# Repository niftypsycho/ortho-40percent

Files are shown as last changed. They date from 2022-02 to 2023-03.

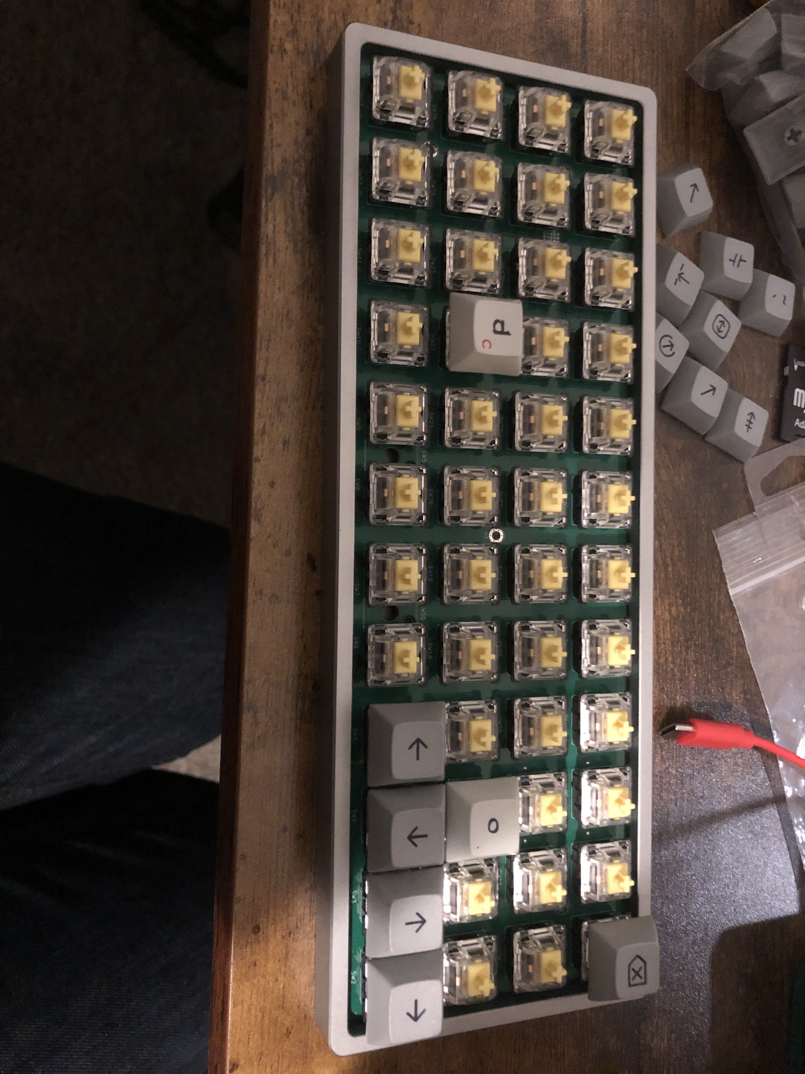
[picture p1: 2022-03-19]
images/IMG_2474.JPG

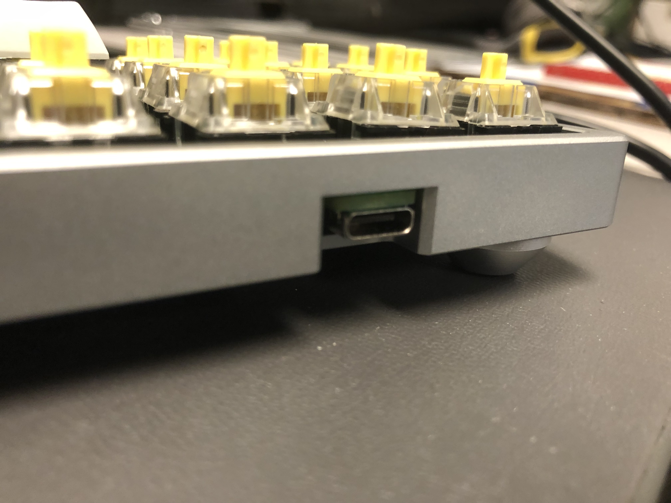
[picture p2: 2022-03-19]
images/IMG_2481.JPG

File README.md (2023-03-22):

# ortho-40percent
 A 40% ortholinear mechanical keyboard with hotswaps. Designed to become familiar with keyboard fabrication and remove the need for soldering.  
 

# INSTRUCTIONS FOR FLASHING  
If you do not already have QMK MSYS installed do so here: https://msys.qmk.fm/  
After installing run `qmk setup`  
Clone the folder labeled mvfang located in the SOFTWARE folder and paste it into qmk_firmware/keyboards  
Test your environment by running `qmk compile -kb mvfang -km default`. This will compile the default keymap included in the mvfang folder.  
  
# EDITING AND FLASHING YOUR KEYMAP  
mvFang uses a nonstandard row-column setup than most custom keyboards. However, this has been basically abstracted away through the config.h and mvfang.h files. Unless you are absolutely certain you know what you are doing you should never interact with those files.  
  
Because this is a hotswap keyboard the option exists to use a single 2u key in the space occupied by the 5th and 6th, and 7th and 8th 1u keys respectively. The config files leave these 2u spaces active as mappable keys during all flashes.  
  
STEP 1 - Create a new keymap  
Copy the `default` keymap by running `qmk new-keymap`. Once it is created open the `keymap.c` file with any text editor. The keycodes are laid out to match the key position with the optional 2 2u keys on the last row. For a list of possible keycodes look at this doc: https://docs.qmk.fm/#/keycodes  
  
STEP 2 - Adding additional layers  
Adding layers is possible as long as you keep the same organization provided in the `LAYOUT_ALL`.  
  
STEP 3 - Flashing your custom keymap  
Make sure the keyboard is not inside the case, or that you have access to the reset button located on the bottom of the board. With the keyboard plugged into your computer double-tap the reset button. You should hear the USB connect noise (if you're on Windows) which means your board is in bootloader mode. Run `qmk flash -kb mvfang -km <my_keymap>`. If everything completes, congratulations.

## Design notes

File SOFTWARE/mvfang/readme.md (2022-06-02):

# mvfang

mvfang

*A short description of the keyboard/project*

* Keyboard Maintainer: [Christian Pavkovich](https://github.com/niftypsycho)
* Hardware Supported: *The PCBs, controllers supported*
* Hardware Availability: *Links to where you can find this hardware*

Make example for this keyboard (after setting up your build environment):

    make mvfang:default

Flashing example for this keyboard:

    make mvfang:default:flash

See the [build environment setup](https://docs.qmk.fm/#/getting_started_build_tools) and the [make instructions](https://docs.qmk.fm/#/getting_started_make_guide) for more information. Brand new to QMK? Start with our [Complete Newbs Guide](https://docs.qmk.fm/#/newbs).

## Bootloader

Enter the bootloader in 3 ways:

* **Bootmagic reset**: Hold down the key at (0,0) in the matrix (usually the top left key or Escape) and plug in the keyboard
* **Physical reset button**: Briefly press the button on the back of the PCB - some may have pads you must short instead
* **Keycode in layout**: Press the key mapped to `RESET` if it is available

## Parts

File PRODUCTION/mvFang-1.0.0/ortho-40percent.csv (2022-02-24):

Source: | C:\Users\Christian\Documents\GitHub\ortho-40percent\ortho-40percent.sch
Date: | 7/28/2021 2:41:26 PM
Tool: | Eeschema (5.1.4)-1
Generator: | C:\Program Files\KiCad\bin\scripting\plugins/bom_csv_grouped_by_value_with_fp.py
Component Count: | 128
Qnty | Ref | Manufacturer | MPN | Package | Description
1 | C3, | KEMET | T520A106M010ATE080 | 1206
8 | C4, C6, C7, C8, C9, C1, C2, C5, | KEMET | C0805C104M5RACTU | 0805
50 | D1, D8, D15, D22, D29, D35, D41, D2, D9, D16, D23, D30, D42, D3, D10, D17, D24, D31, D37, D43, D49, D4, D11, D18, D25, D32, D38, D44, D50, D5, D12, D19, D26, D33, D39, D45, D6, D13, D20, D34, D40, D46, D7, D14, D21, D28, D27, D48, D47, D36, | SMC Diode Solutions | 1N4148WTR | SOD-123
1 | F1, | Bel Fuse Inc. | 0ZCJ0050FF2G | 1206 | Fuse
5 | H1, H2, H3, H4, H5, | DNP | DNP | DNP
1 | J1, | Amphenol ICC (Commercial Products) | 12401598E4#2A | Surface Mount, Right Angle; Through Hole
1 | L1, | Taiyo Yuden | FBMJ3216HM600-T | 1206
6 | R1, R2, R4, R3, R6, R5, | Yageo | RC0805FR-0710KL | 0805
1 | SW1, | C&K | RS-187R05A2-DS MT RT | Surface Mount
48 | SW2, SW9, SW16, SW23, SW30, SW36, SW42, SW3, SW10, SW17, SW24, SW31, SW43, SW4, SW11, SW18, SW25, SW32, SW38, SW44, SW5, SW12, SW19, SW26, SW33, SW39, SW45, SW6, SW13, SW20, SW27, SW34, SW40, SW46, SW7, SW14, SW21, SW35, SW41, SW47, SW8, SW15, SW22, SW29, SW28, SW49, SW48, SW37, | DNP | DNP | 1u
2 | SW50, SW51, | DNP | DNP | 2u
1 | TVS1, | Rohm Semiconductor | SMF6V0TFTR | SOD-123F
1 | U1, | Texas Instruments | TPD4E05U06DQAR | UFDFN-10 | TVS DIODE 5.5V 14V 10SON
1 | U2, | Microchip Technology | ATMEGA32U4-MU | VQFN-44-1EP | IC MCU 8BIT 32KB FLASH 44VQFN
1 | Y1, | Kyocera International Inc. Electronic Components | CX3225SB16000D0GZJC1 | 4-SMD | Generic crystal with 4 leads

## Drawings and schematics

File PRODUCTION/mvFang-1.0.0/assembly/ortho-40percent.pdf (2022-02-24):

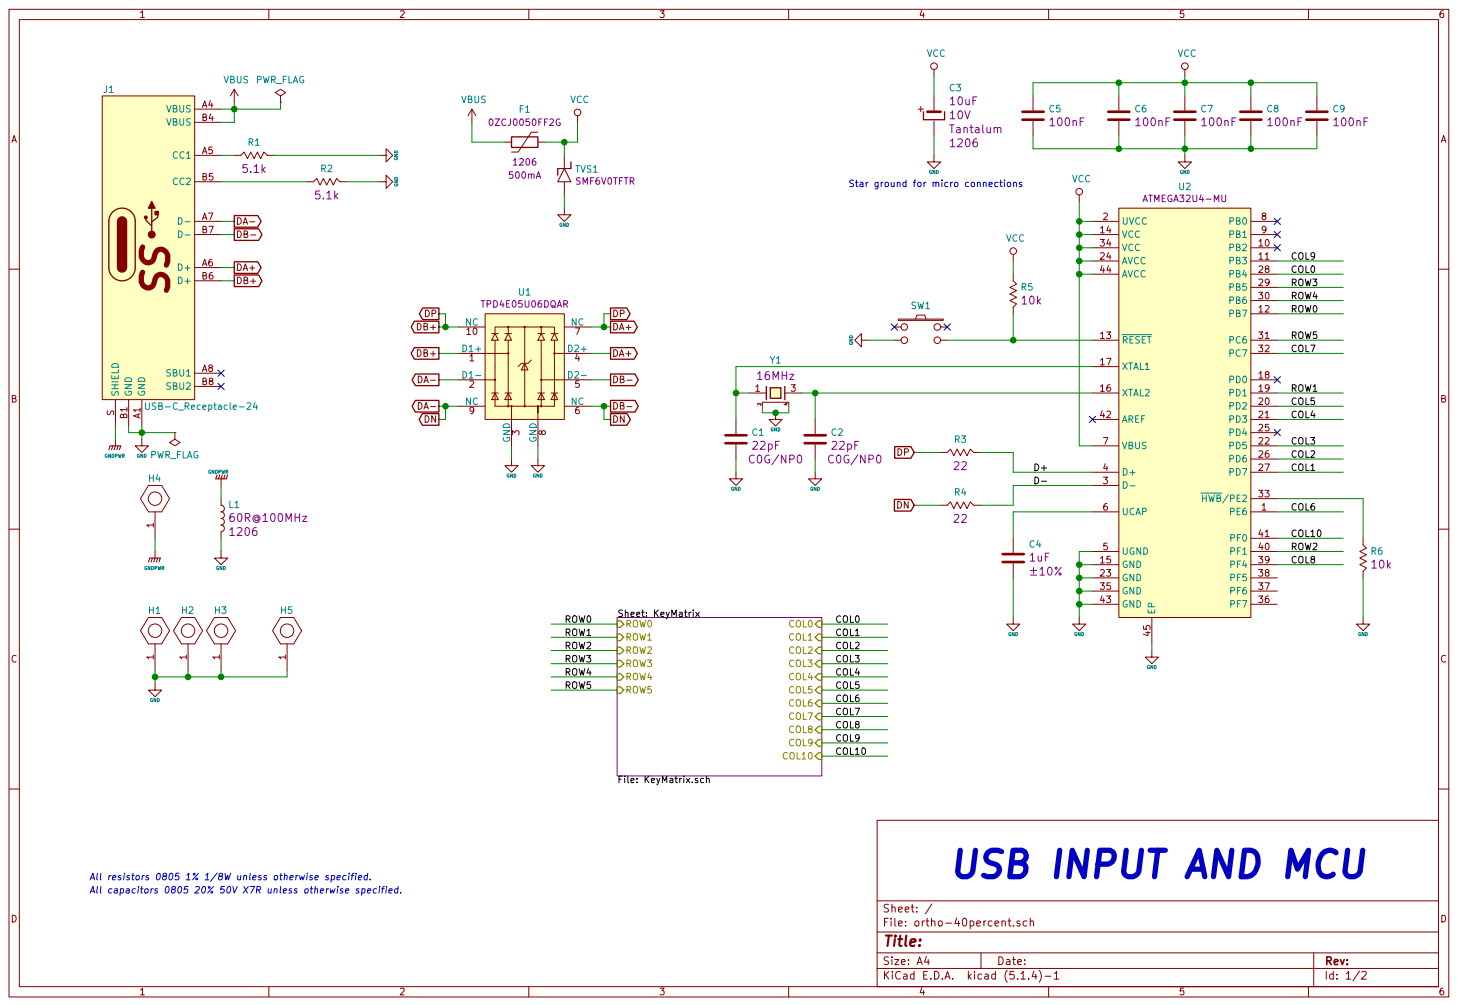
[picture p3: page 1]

Star ground for micro connections

File: ortho-40percent.sch Sheet: / Sheet: KeyMatrix

USB INPUT AND MCU

All capacitors 0805 20% 50V X7R unless otherwise specified.

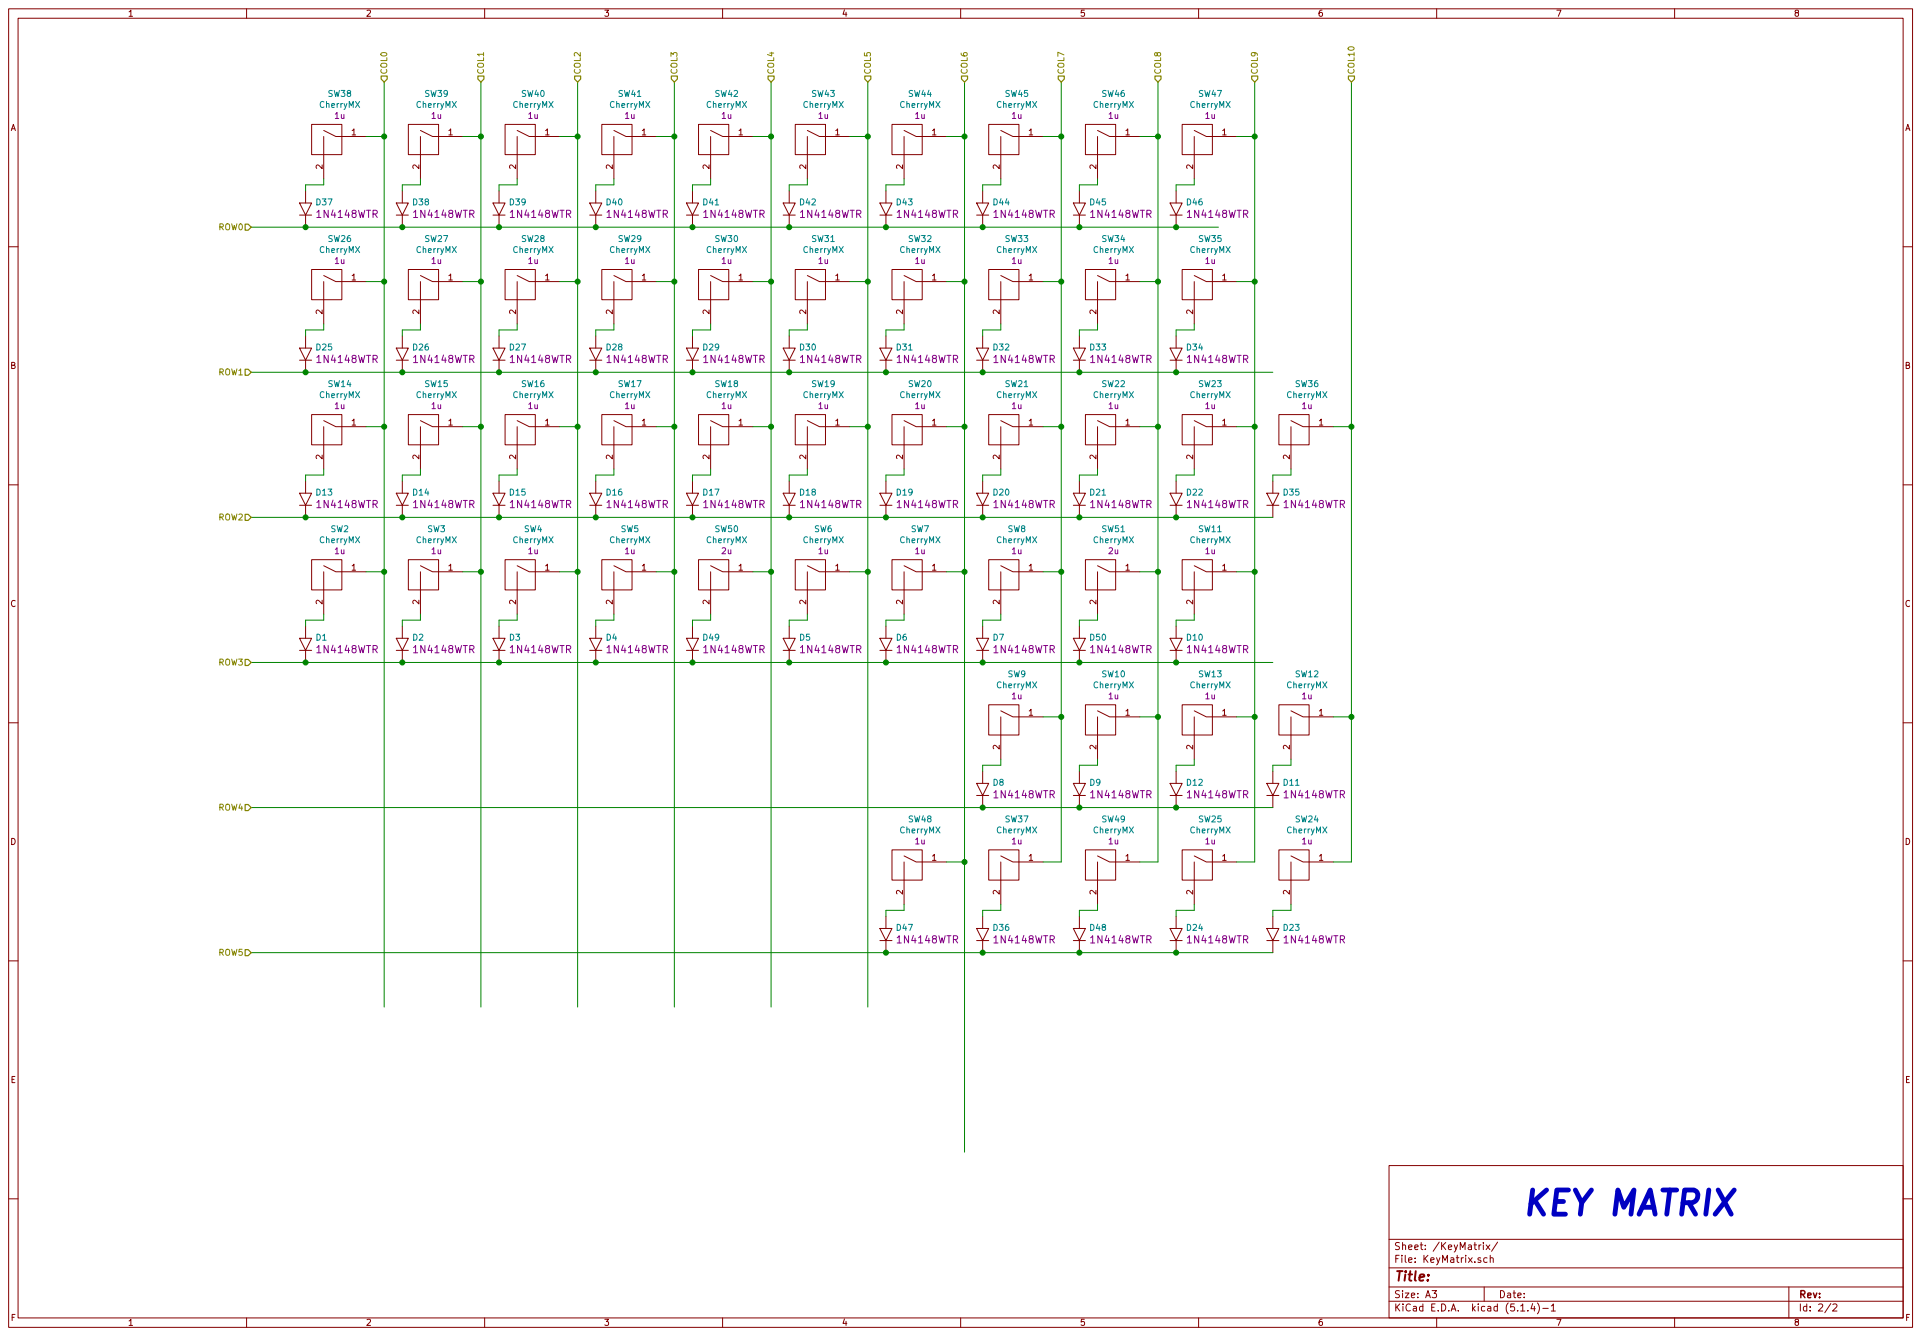
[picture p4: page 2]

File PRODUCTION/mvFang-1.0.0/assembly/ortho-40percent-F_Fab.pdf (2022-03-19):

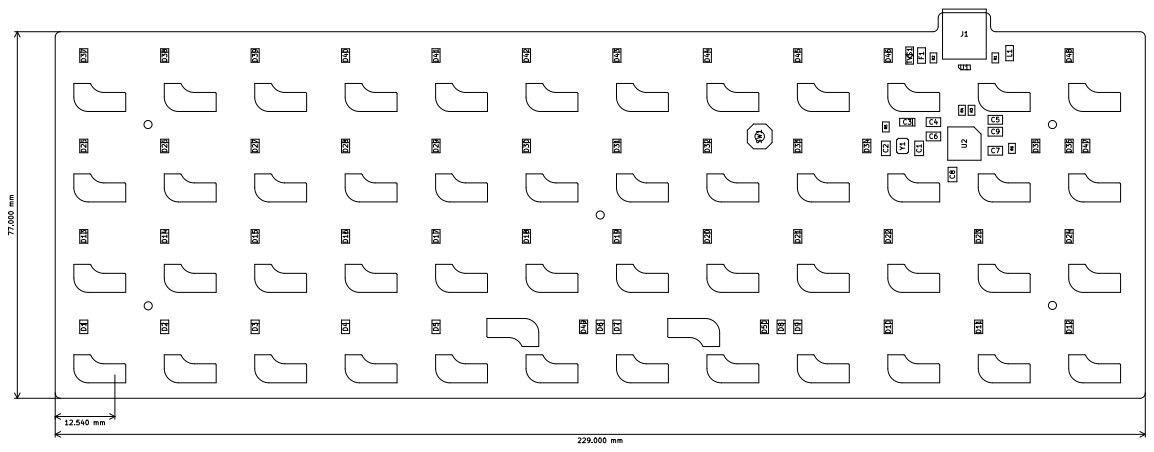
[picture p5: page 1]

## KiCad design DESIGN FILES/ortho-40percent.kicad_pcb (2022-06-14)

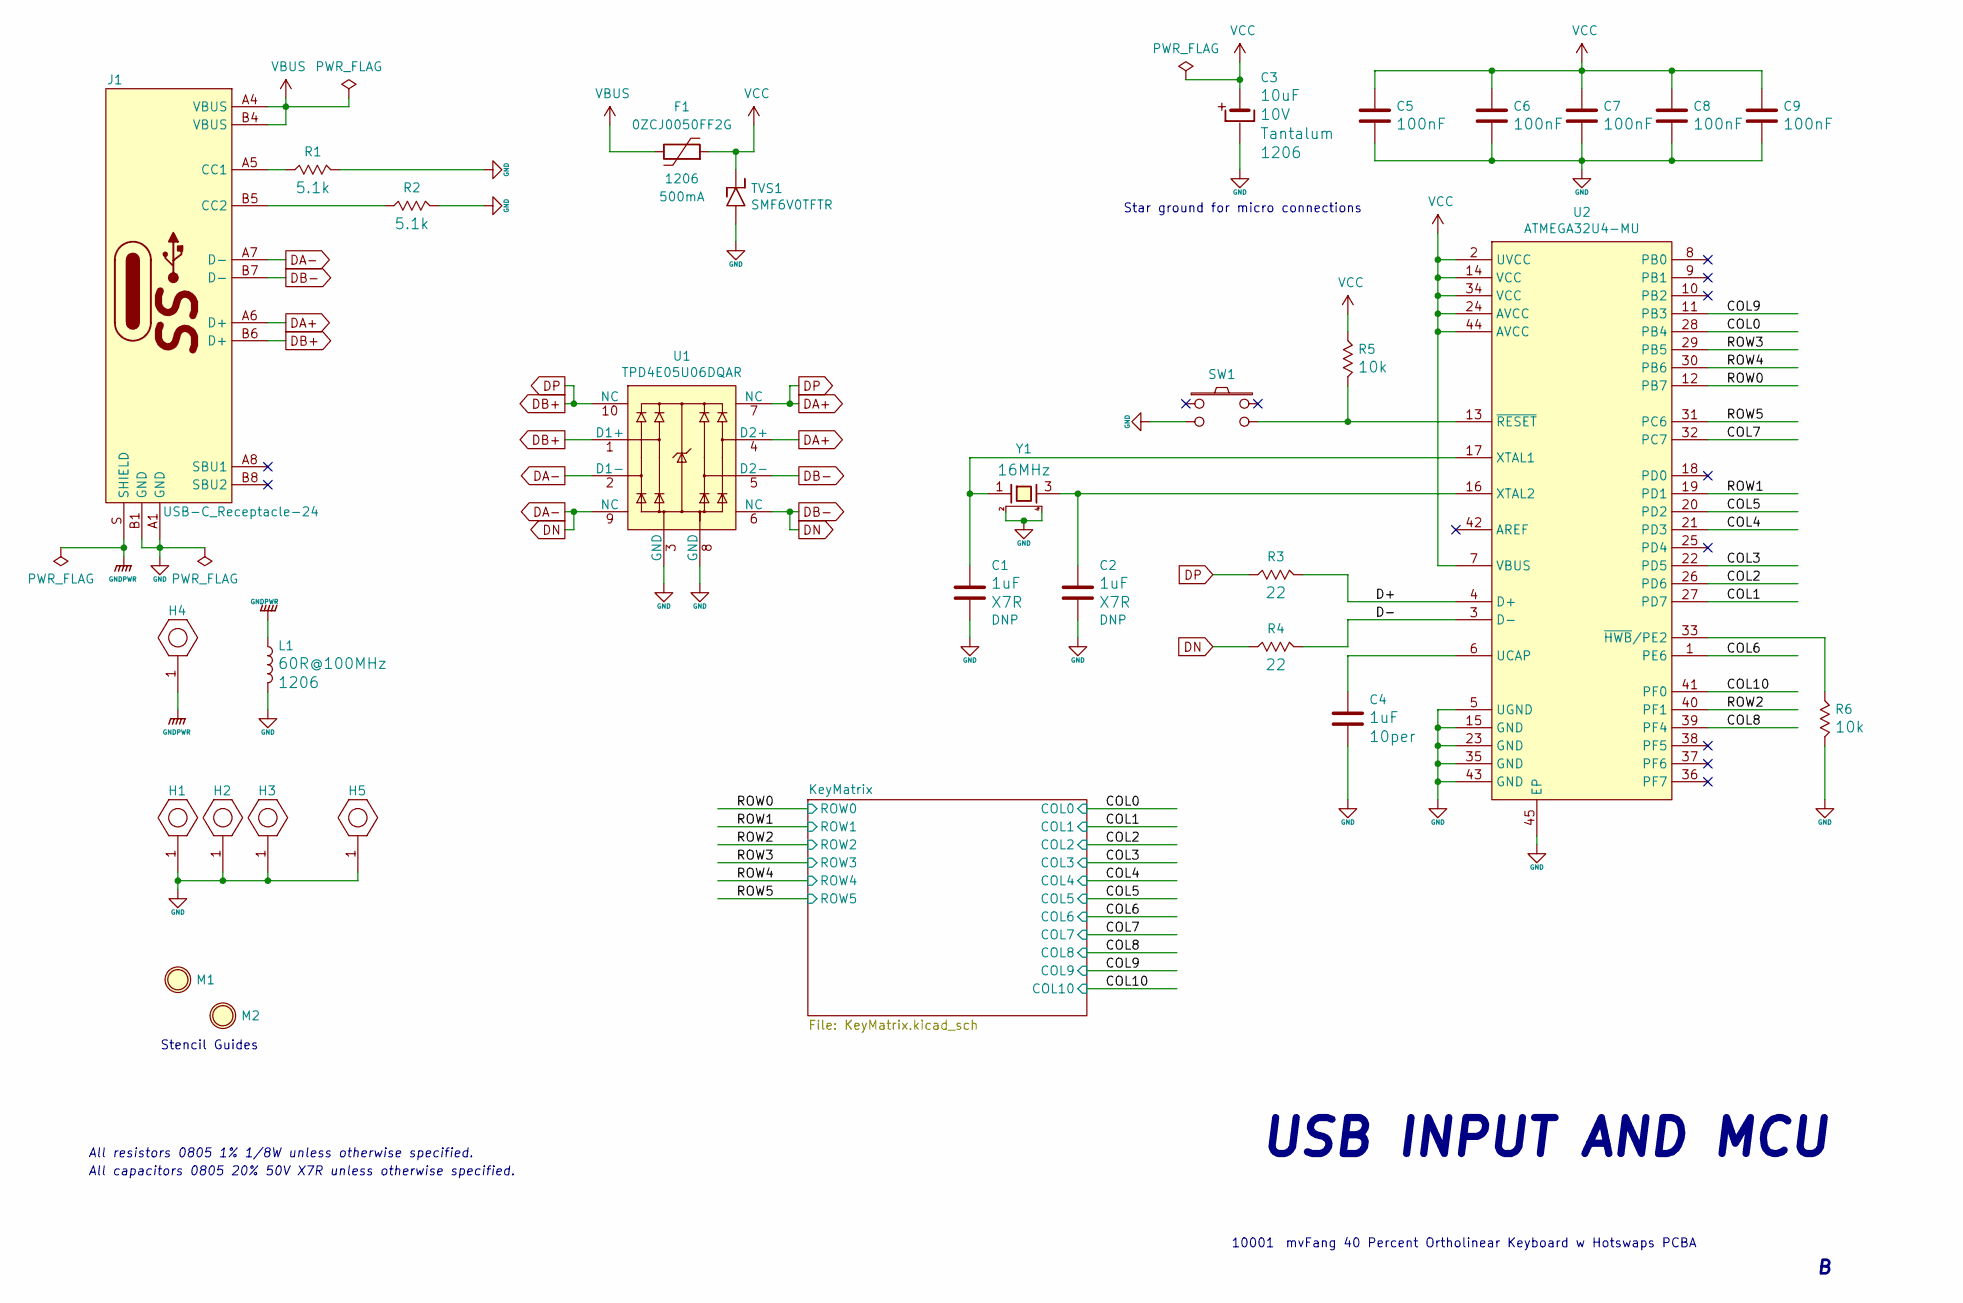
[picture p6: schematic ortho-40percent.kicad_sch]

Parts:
C1, C2: C; C_0805; Voltage Rating 50V; Tolerance 20per; MPN DNP
C3: CP_tantalum; CP_TANTALUM_1206; Voltage Rating 10V; Tolerance 20per; MPN T520A106M010ATE080
C4: C; C_0805; Voltage Rating 50V; Tolerance 10per; MPN CL21B105KBFNNNG
C5: C; C_0805; Voltage Rating 50V; Tolerance 20per; MPN C0805C104M5RACTU
C6, C7, C8, C9: C; C_0805; Voltage Rating 50V; Tolerance ±20%; MPN C0805C104M5RACTU
F1: F; F_1206; MPN 0ZCJ0050FF2G
H1, H2, H3, H4, H5: H_MountingHole_Screw_withPin; H_Screw-M2_Countersunk; MPN DNP
J1: USB-C_Receptacle-24; USB-C_Amphenol_12401598E4; MPN DNP
L1: L; L_1206; Current Rating 4A; Tolerance 20per; MPN FBMJ3216HM600-T
M1, M2: M_StencilGuide; STENCIL_GUIDE_HOLE; MPN DNP
R1, R2: R; R_0805; Tolerance 1per; MPN ERJ-6ENF5101V
R3, R4: R; R_0805; Tolerance 1per; MPN RC0805FR-0722RL
R5, R6: R; R_0805; Tolerance 1per; MPN RC0805FR-0710KL
SW1: SW_NO_4-Pin; SW_C+K_4-SMD-Gullwing_5.2x5.2mm_H1.6mm; MPN RS-187R05A2-DS MT RT
TVS1: TVS_Unidirectional; SOD-123F; MPN SMF6V0TFTR
U1: U_TPD4E05U06DQAR; UFDFN-10; MPN TPD4E05U06DQAR
U2: U_ATmega32u4-MU; VQFN-44-1EP_7x7mm_P0.5mm_ThermalVias; MPN ATMEGA32U4-MU
Y1: XTAL_4Lead; XTAL_4-SMD_3.2x2.5mm; MPN CX3225SB16000D0GZJC1

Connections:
/COL0: U2.28 (PB4); also elsewhere on the board
/COL1: U2.27 (PD7); also elsewhere on the board
/COL2: U2.26 (PD6); also elsewhere on the board
/COL3: U2.22 (PD5); also elsewhere on the board
/COL4: U2.21 (PD3); also elsewhere on the board
/COL5: U2.20 (PD2); also elsewhere on the board
/COL6: U2.1 (PE6); also elsewhere on the board
/COL7: U2.32 (PC7); also elsewhere on the board
/COL8: U2.39 (PF4); also elsewhere on the board
/COL9: U2.11 (PB3); also elsewhere on the board
/COL10: U2.41 (PF0); also elsewhere on the board
/D+: R3.1, U2.4 (D+)
/D-: R4.1, U2.3 (D-)
/ROW0: U2.12 (PB7); also elsewhere on the board
/ROW1: U2.19 (PD1); also elsewhere on the board
/ROW2: U2.40 (PF1); also elsewhere on the board
/ROW3: U2.29 (PB5); also elsewhere on the board
/ROW4: U2.30 (PB6); also elsewhere on the board
/ROW5: U2.31 (PC6); also elsewhere on the board
DA+: J1.A6 (D+), J1.B6 (D+), R3.2, U1.1 (D1+), U1.4 (D2+), U1.7 (NC), U1.10 (NC)
DA-: J1.A7 (D-), J1.B7 (D-), R4.2, U1.2 (D1-), U1.5 (D2-), U1.6 (NC), U1.9 (NC)
GND: C1.2, C2.2, C3.2, C4.2, C5.2, C6.2, C7.2, C8.2, C9.2, H1.1, H2.1, H3.1, H5.1, J1.A1 (GND), J1.B1 (GND), L1.2, R1.1, R2.1, R6.1, SW1.2 (in), TVS1.A, U1.3 (GND), U1.8 (GND), U2.5 (UGND), U2.15 (GND), U2.23 (GND), U2.35 (GND), U2.43 (GND), U2.45 (EP), Y1.2 (case), Y1.4 (case)
GNDPWR: H4.1, J1.S (SHIELD), L1.1
unnamed: C1.1, U2.17 (XTAL1), Y1.1
unnamed: C2.1, U2.16 (XTAL2), Y1.3
unnamed: C4.1, U2.6 (UCAP)
unnamed: J1.A5 (CC1), R1.2
unnamed: J1.B5 (CC2), R2.2
unnamed: R5.1, SW1.4 (out), U2.13 (~RESET)
unnamed: R6.2, U2.33 (~HWB/PE2)
VBUS: F1.1, J1.A4 (VBUS), J1.B4 (VBUS)
VCC: C3.1, C5.1, C6.1, C7.1, C8.1, C9.1, F1.2, R5.2, TVS1.K, U2.2 (UVCC), U2.7 (VBUS), U2.14 (VCC), U2.24 (AVCC), U2.34 (VCC), U2.44 (AVCC)

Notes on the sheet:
10001
All resistors 0805 1% 1/8W unless otherwise specified.
All capacitors 0805 20% 50V X7R unless otherwise specified.
USB INPUT AND MCU
mvFang 40 Percent Ortholinear Keyboard w Hotswaps PCBA
Star ground for micro connections
Stencil Guides

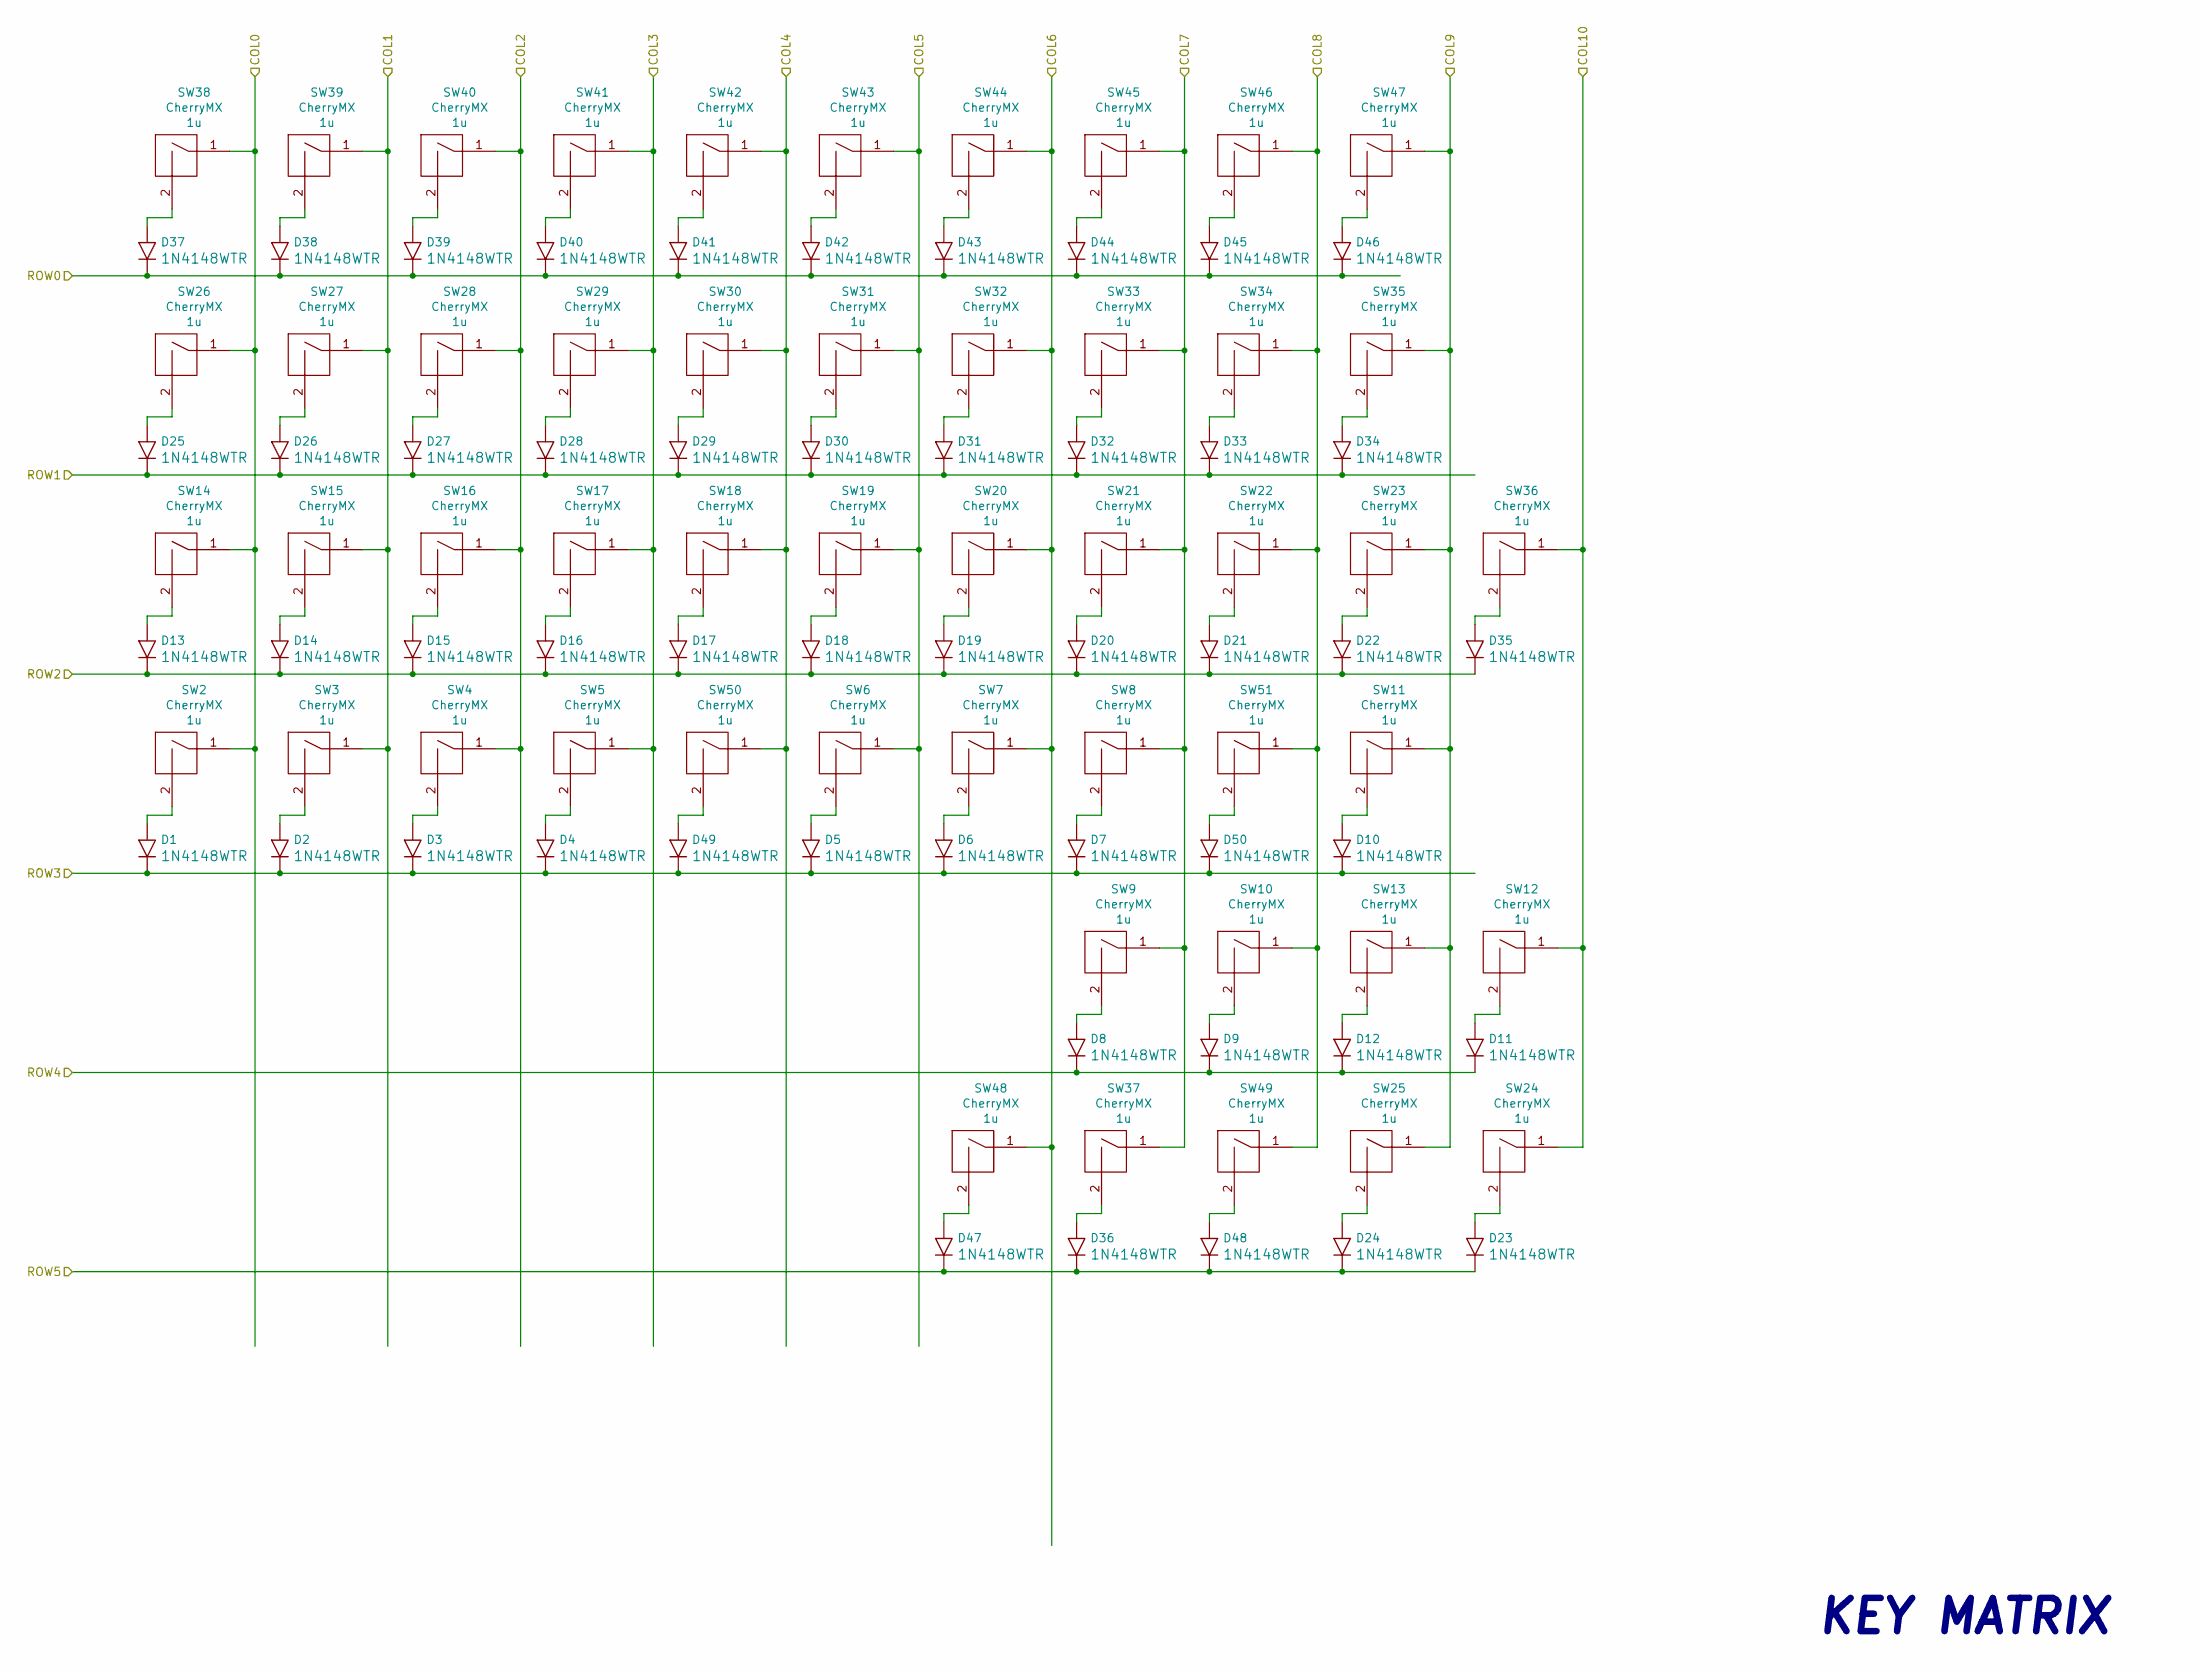
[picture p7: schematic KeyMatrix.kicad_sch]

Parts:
D1, D2, D3, D4, D5, D6, D7, D8, D9, D10, D11, D12, D13, D14, D15, D16, D17, D18, D19, D20, D21, D22, D23, D24, D25, D26, D27, D28, D29, D30, D31, D32, D33, D34, D35, D36, D37, D38, D39, D40, D41, D42, D43, D44, D45, D46, D47, D48, D49, D50: D; SOD-123; Voltage Rating 75V; Current Rating 250mA; MPN 1N4148WTR
SW2, SW3, SW4, SW5, SW6, SW7, SW8, SW9, SW10, SW11, SW12, SW13, SW14, SW15, SW16, SW17, SW18, SW19, SW20, SW21, SW22, SW23, SW24, SW25, SW26, SW27, SW28, SW29, SW30, SW31, SW32, SW33, SW34, SW35, SW36, SW37, SW38, SW39, SW40, SW41, SW42, SW43, SW44, SW45, SW46, SW47, SW48, SW49: CherryMX; SW_Cherry-MX_1U_PCB-Mount_Kailh-Hot-Swap; MPN DNP
SW50, SW51: CherryMX; SW_Cherry-MX_2U_PCB-Mount_Kailh-Hot-Swap; MPN DNP

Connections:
/COL0: SW2.1 (COL), SW14.1 (COL), SW26.1 (COL), SW38.1 (COL); also elsewhere on the board
/COL1: SW3.1 (COL), SW15.1 (COL), SW27.1 (COL), SW39.1 (COL); also elsewhere on the board
/COL2: SW4.1 (COL), SW16.1 (COL), SW28.1 (COL), SW40.1 (COL); also elsewhere on the board
/COL3: SW5.1 (COL), SW17.1 (COL), SW29.1 (COL), SW41.1 (COL); also elsewhere on the board
/COL4: SW18.1 (COL), SW30.1 (COL), SW42.1 (COL), SW50.1 (COL); also elsewhere on the board
/COL5: SW6.1 (COL), SW19.1 (COL), SW31.1 (COL), SW43.1 (COL); also elsewhere on the board
/COL6: SW7.1 (COL), SW20.1 (COL), SW32.1 (COL), SW44.1 (COL), SW48.1 (COL); also elsewhere on the board
/COL7: SW8.1 (COL), SW9.1 (COL), SW21.1 (COL), SW33.1 (COL), SW37.1 (COL), SW45.1 (COL); also elsewhere on the board
/COL8: SW10.1 (COL), SW22.1 (COL), SW34.1 (COL), SW46.1 (COL), SW49.1 (COL), SW51.1 (COL); also elsewhere on the board
/COL9: SW11.1 (COL), SW13.1 (COL), SW23.1 (COL), SW25.1 (COL), SW35.1 (COL), SW47.1 (COL); also elsewhere on the board
/COL10: SW12.1 (COL), SW24.1 (COL), SW36.1 (COL); also elsewhere on the board
/ROW0: D37.K, D38.K, D39.K, D40.K, D41.K, D42.K, D43.K, D44.K, D45.K, D46.K; also elsewhere on the board
/ROW1: D25.K, D26.K, D27.K, D28.K, D29.K, D30.K, D31.K, D32.K, D33.K, D34.K; also elsewhere on the board
/ROW2: D13.K, D14.K, D15.K, D16.K, D17.K, D18.K, D19.K, D20.K, D21.K, D22.K, D35.K; also elsewhere on the board
/ROW3: D1.K, D2.K, D3.K, D4.K, D5.K, D6.K, D7.K, D10.K, D49.K, D50.K; also elsewhere on the board
/ROW4: D8.K, D9.K, D11.K, D12.K; also elsewhere on the board
/ROW5: D23.K, D24.K, D36.K, D47.K, D48.K; also elsewhere on the board
unnamed: D1.A, SW2.2 (ROW)
unnamed: D2.A, SW3.2 (ROW)
unnamed: D3.A, SW4.2 (ROW)
unnamed: D4.A, SW5.2 (ROW)
unnamed: D5.A, SW6.2 (ROW)
unnamed: D6.A, SW7.2 (ROW)
unnamed: D7.A, SW8.2 (ROW)
unnamed: D8.A, SW9.2 (ROW)
unnamed: D9.A, SW10.2 (ROW)
unnamed: D10.A, SW11.2 (ROW)
unnamed: D11.A, SW12.2 (ROW)
unnamed: D12.A, SW13.2 (ROW)
unnamed: D13.A, SW14.2 (ROW)
unnamed: D14.A, SW15.2 (ROW)
unnamed: D15.A, SW16.2 (ROW)
unnamed: D16.A, SW17.2 (ROW)
unnamed: D17.A, SW18.2 (ROW)
unnamed: D18.A, SW19.2 (ROW)
unnamed: D19.A, SW20.2 (ROW)
unnamed: D20.A, SW21.2 (ROW)
unnamed: D21.A, SW22.2 (ROW)
unnamed: D22.A, SW23.2 (ROW)
unnamed: D23.A, SW24.2 (ROW)
unnamed: D24.A, SW25.2 (ROW)
unnamed: D25.A, SW26.2 (ROW)
unnamed: D26.A, SW27.2 (ROW)
unnamed: D27.A, SW28.2 (ROW)
unnamed: D28.A, SW29.2 (ROW)
unnamed: D29.A, SW30.2 (ROW)
unnamed: D30.A, SW31.2 (ROW)
unnamed: D31.A, SW32.2 (ROW)
unnamed: D32.A, SW33.2 (ROW)
unnamed: D33.A, SW34.2 (ROW)
unnamed: D34.A, SW35.2 (ROW)
unnamed: D35.A, SW36.2 (ROW)
unnamed: D36.A, SW37.2 (ROW)
unnamed: D37.A, SW38.2 (ROW)
unnamed: D38.A, SW39.2 (ROW)
unnamed: D39.A, SW40.2 (ROW)
unnamed: D40.A, SW41.2 (ROW)
unnamed: D41.A, SW42.2 (ROW)
unnamed: D42.A, SW43.2 (ROW)
unnamed: D43.A, SW44.2 (ROW)
unnamed: D44.A, SW45.2 (ROW)
unnamed: D45.A, SW46.2 (ROW)
unnamed: D46.A, SW47.2 (ROW)
unnamed: D47.A, SW48.2 (ROW)
unnamed: D48.A, SW49.2 (ROW)
unnamed: D49.A, SW50.2 (ROW)
unnamed: D50.A, SW51.2 (ROW)

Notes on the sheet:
KEY MATRIX

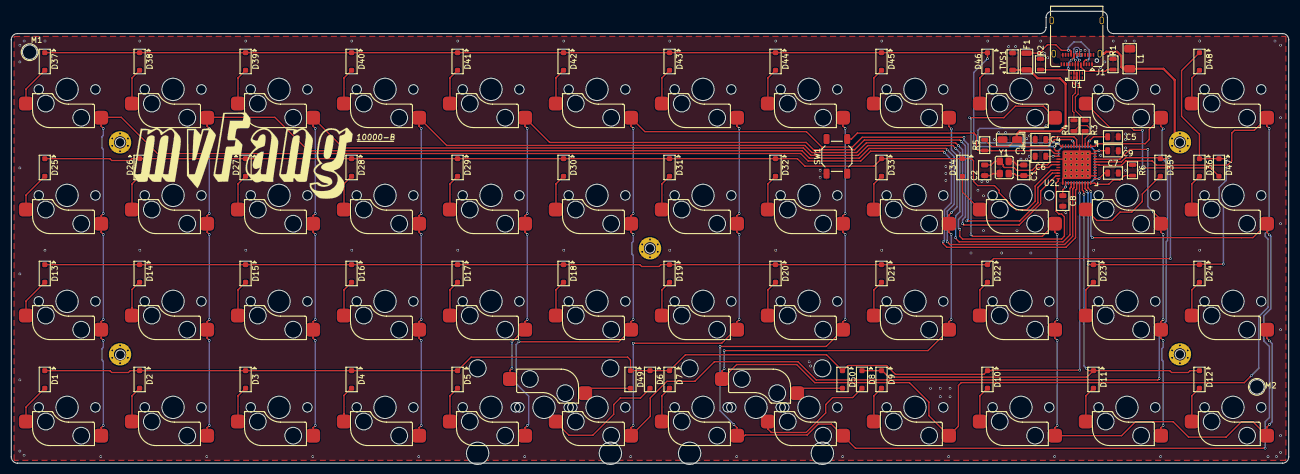
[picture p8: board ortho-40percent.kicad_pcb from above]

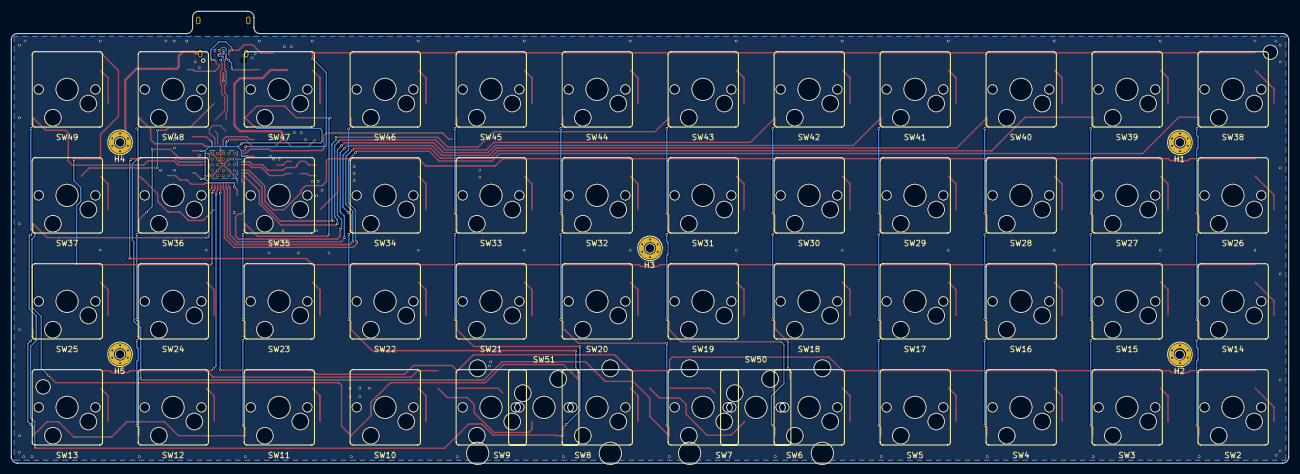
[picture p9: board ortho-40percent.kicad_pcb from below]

Board: 2 copper layers, 229.0 x 81.0 mm, 130 parts (55 on the bottom side), 82 nets.

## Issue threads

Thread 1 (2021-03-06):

Micro is too big

niftypsycho, 2021-03-06:
Not possible to fit current microcontroller package on the board. Either choose smaller micro or smaller package.

niftypsycho, 2021-03-12:
Smallest ATMega32u4 is a 44-VQFN at 7x7mm. The current package is a 44-TQFP at 10x10mm. This package size fits easily between two switches.

Closed 2021-04-14.

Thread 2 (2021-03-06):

Mounting hole ground connection

niftypsycho, 2021-03-06:
Mounting holes need to be connected to some ground, chassis or signal. Need to synchronize with how usb-c shield is grounded.

niftypsycho, 2021-03-12:
Grounding scheme decided, included in most recent push.

niftypsycho, 2021-03-12:
Grounding scheme decidded, fixed in most recent push.

Closed 2021-03-12.

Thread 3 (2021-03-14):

PCB edge is not centered completely

niftypsycho, 2021-03-14:
Center mounting hole should ideally be in the center of the PCB. The keyswitches also are barely not centered.

niftypsycho, 2021-04-14:
Fixed

Closed 2021-04-14.

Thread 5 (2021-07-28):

Keyswitch center hole is too small

niftypsycho, 2021-07-28:
Keyswitch footprint center hole is slightly too small, requires force to insert key fully.

niftypsycho, 2021-07-28:
Caliper measurement shows 3.9mm, MX datasheets specify 4mm hole size with 0.1mm tolerance. Might be necessary to call out tolerance in fabrication layer or notes.

niftypsycho, 2022-03-28:
Center hole was not an issue in final design.

Closed 2022-03-28.

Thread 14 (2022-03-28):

DIP switch for no-solder spacebar swap

niftypsycho, 2022-03-28:
Currently the board has hotswaps for a full 1u ortholinear setup, as well as hotswaps for 2 2u keys where the spacebar usually is mapped. This means the software is setup to read those switches in the matrix position and gives the user the option to change on the fly. In order to make the software more standard and map only to keys that are being used, it could be beneficial to keep assembling board with all hotwaps in place as before but add a low-profile DIP switch to switch between the 1u and 2u setups. The MINIMUM distance between the top of board and the back of the KPRepublic case is 3.5mm so the DIP switch must have a height above board of less than that.

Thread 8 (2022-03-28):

Add stencil guide holes

niftypsycho, 2022-03-28:
No-cost way to ensure stencil is aligned for reflow soldering. 2.6mm diameter holes that accept 2.5mm metal dowels near opposite ends of the board and set as paste layer. Would align to 10mm hole grid drilled in some flat frame.

niftypsycho, 2022-04-04:
Added

Closed 2022-04-04.

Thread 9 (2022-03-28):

Fix diode mark legibility

niftypsycho, 2022-03-28:
Some diode polarity markings are not visible due to logo and other silkscreen items.

niftypsycho, 2022-04-18:
Fixed diode D26 and D27

Closed 2022-04-18.

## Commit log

2020-07-23 Initialize Project
    Created KiCad project.
    [ortho-40percent.kicad_pcb, ortho-40percent.sch]
2020-07-24 Footprint library creation
    Began creation of mx 1u footprint
2020-07-26 Switch footprint completion
    Completed cherry mx switch footprints - Plate mount, pcb mount, and kailh hot swap swich variants
2020-07-30 Footprint creation
    Created ortho-40percent footprint library. Created footprints for 1206 fuse, usb-c tvs, and 1206 inductor. Modified SOD-123F from different library. Created USB-C footprint.
2020-09-26 Created KeyMatrix schematic
    Added new footprints and associated 3d models. Created KeyMatrix schematic sheet.
    [KeyMatrix.sch, ortho-40percent.sch]
2020-09-26 Clarified Keycaps
    Added drawing outline of DSA keycap dimension. Added DSA keycap 3d model to 1u mx pcbmount switch. Placed two rows of switches on pcb layout.
    [ortho-40percent.kicad_pcb]
2020-10-07 PCB Key Layout
    Locked placement of main key matrix on pcb, began placement of matrix diodes.
    [ortho-40percent.kicad_pcb]
2021-03-05 Case outline and mounting
    Received kprepublic case, used dimensions to set drawing of case and pcb outline. Created M2 screw footprint and added mounting holes to project. Tied screws to power gnd, will possibly change to sig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
    [KeyMatrix.sch, ortho-40percent.kicad_pcb, ortho-40percent.sch]
2021-03-08 ESD overhaul and mechanical finish
    Finished mounting hole placement with respect to case dimensions. Rotated all switches 180 to allow for placement of USB-C connector. Redid ground connections to have connector shield grounded to case and signal ground grounded to case, but not connected on PCB. Added tab on PCB edge to allow USB-C connector to extend further out of case. Replaced 9V TVS with 6V TVS.
    [ortho-40percent.kicad_pcb, ortho-40percent.sch]
2021-03-13 2u footprint and plate comments
    Finished 2u footprint in all styles. Added cutouts by using Cmts.User layer.
    [KeyMatrix.sch, ortho-40percent.kicad_pcb, ortho-40percent.sch]
2021-03-16 Fixed case, pcb, screw locations
    Set origin to hole on bottom-left switch, based all pcb and case dimensions on that hole. Relocated screws to new locations, now they are symmetrical with key positions.
    [KeyMatrix.sch, ortho-40percent.kicad_pcb]
2021-04-14 Micro change and origin reset
    Returned origin to center hole of bottom-left switch instead of pin 1 hole.
    Added 3mm ground trace margin and mtg hole margin.
    Created 44-VQFN footprint and schematic symbol, and updated micro to new part.
    [ortho-40percent.kicad_pcb, ortho-40percent.sch]
2021-04-28 USB connector update
    Added connector keepout zone and PCB edge text for usb-c connector footprint. Attempted routing and movement of D+/D- lines.
    [ortho-40percent.kicad_pcb, ortho-40percent.sch]
2021-04-30 Routing
    more routing and placement
    [ortho-40percent.kicad_pcb]
2021-04-30 USB connections
    Completed USB-C routing, tested ground planes and settings for robustness
    [ortho-40percent.kicad_pcb]
2021-05-02 Beginning switch routing
    Finished routing of all micro, usb, and power components. Beginning placement and routing of diodes and keyswitches.
    [ortho-40percent.kicad_pcb, ortho-40percent.sch]
2021-05-03 More key routing
    Remapped keys to rows/columns to help optimize. Routed more.
    [KeyMatrix.sch, ortho-40percent.kicad_pcb, ortho-40percent.sch]
2021-05-04 More routing
    more routing
    [ortho-40percent.kicad_pcb]
2021-05-18 More routing
    even more routing
    [KeyMatrix.sch, ortho-40percent.kicad_pcb]
2021-07-11 Routing Finished
    All connections routed. Focusing on cleaning up for length optimization and minimal bottom plane cutting.
    [ortho-40percent.kicad_pcb, ortho-40percent.sch]
2021-07-12 Electrical Finished
    All electrical completed, refdes placed. Beginning to place silkscreen logos and other branding items.
    [ortho-40percent.kicad_pcb, ortho-40percent.sch]
2021-07-17 Hardware Complete
    Electrical completed and DRC passed.
    Silkscreen logos and info added.
    Ready for first prototype ordering.
    [ortho-40percent.kicad_pcb]
2021-07-18 Mounting hole modifications
    Drilled holes for mounting holes were smaller than 0.3mm which many boardhouses charge extra for. Increased hole size to 0.33mm.
    [ortho-40percent-B_Cu.gbr, ortho-40percent-B_Fab.gbr, ortho-40percent-B_Mask.gbr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]
2022-02-24 Created and modified fabrication
    Created more sensical fabrication and assembly outputs. Differentiated between first revision and subsequent revisions.
    [ortho-40percent-B_Cu.gbr, ortho-40percent-B_Fab.gbr, ortho-40percent-B_Mask.gbr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]
2022-03-19 Consolidating design files
    Added directory to store design separate from production files
    [KeyMatrix.sch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]
2022-04-04 Added stencil guide holes
    Added 2.6mm dia guide holes at 10mm spacings to board to help with stencil alignment
    [ortho-40percent.kicad_pcb, ortho-40percent.sch]
2022-04-18 Fixed diode legibility
    Issue affected D26 and D27 and is fixed
    [ortho-40percent.kicad_pcb]
2022-04-18 Added custom MV PNs to each component
    Added unique MV PN for each unique component, referenced in personal component database.
    [KeyMatrix.sch, ortho-40percent.sch]
2022-06-14 Added .gitignore
    Stops tracking backups and auto generated KiCad files
    [KeyMatrix.kicad_sch, ortho-40percent.kicad_pcb, ortho-40percent.kicad_sch]
